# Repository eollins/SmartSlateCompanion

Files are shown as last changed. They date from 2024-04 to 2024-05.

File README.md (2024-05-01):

Introduction
--

[Smart Slate Github Repo](https://github.com/eollins/SmartSlateCompanion/tree/master)

Team Members: Ethan Ollins, Jack Cochran, Alex Peng

For our 4180 project we decided to make our own version of an IOT enabled slate used for film productions. These "Smart Slates", as we have called them, have 6 primary functions.
They are:

1) Display the Roll, Scene, and Take number.
  
2) Keep track of the current time relative to the start of the shoot.
   
3) Keep track of the timestamp of the start of each scene.
   
4) Make it easy for the Assistant Director(will now be referenced as AD) to take notes on the current scene and save them for use while editing.
   
5) Make a nice clap sound in order to sync up the video and audio tracks.
    
6) Automatic time start and stop based on clap

For the purposes of designing this project we broke the problem up into 3 segments: detecting the clap and displaying relevant info, controling the slate and inputting relevant info, and the means with which the AD interfaces with the Smart Slate™️. To accomplish this we decided to not only create a Smart Slate™️ but also a desktop companion app that the AD can use to take notes and interface with the slate.

<a href="http://youtu.be/_YN7Nneg3RY" target="_blank">//-- Video Demo --//</a>

Electrical and Hardware Design
-

List of Parts:
* Raspberry Pi 3b+
* Mbed microcontroller
* 8x 7 segment displays
* 1x Magnet Sensor
* 3x uLCD
* 8x CD4511BE
* 56x 330 Ohm Resistors
* ABS Filament
* Jumper Wires
* Electrical Tape

Connect the parts as dictated in the wiring diagram, pin numbers are labeled appropriately. The 7 Segment display circuitry along with the CD4511BE are repeated 8 times for each individual part. Each resistor in the diagram is a 330 Ohm resistor for each of the led segments in the 7 segment displays.

SmartSlate

The ULCD's display the Roll, Scene, and Take number. The 7 segment displays displays the time and when the magnet sensor is opened and closed the time is stopped and recorded in the companion software.

Print out the two .stl files in the repository under /3D models and fit components as shown. Secure parts with tape as neccessary.

Slate Front
Slate Back

Software
--
To successfully recreate this project you will need to do the following 5 things.

1) Clone this github repo

2) Set up the raspberry pi to be an access point for a LAN, ensuring it uses a static IP address of 192.168.4.1

3) Take the contents of the folder named raspberry pi and copy them onto your raspberry pi, setting the connectToCompanion.py script to run as a background service

4) Take the contents of the folder named mbed and copy them onto your mbed

5) Download QT Creator and then copy the contents of the folder named gui into a new QT project and compile

The SmartSlate works via three distinct components.

1) Raspberry Pi "connectToCompanion" script
The Raspberry Pi inside the slate hosts a wireless access point using the hostapd and dnsmasq libraries. Through its wireless interface, it uses a static local IP address, 192.168.4.1. The connectToCompanion.py script runs as a background service on the Pi, and it simultaneously listens for and accepts TCP connections from users, monitors connections for heartbeats (allowing for timeout detection), maintains a "slate state," and communicates with the mbed. The Raspberry Pi script is a state machine of sorts, cycling between the states of "init" (when the slate is waiting for take information), "ready" (when the slate has received take information and is waiting for the operator to use the clapper), and "clapped" (when the slate has been clapped, the timecode has been reported, and the slate is waiting for notes to be published). The Pi script additionally saves all notes and updates made to them in a local tab-separated values file, which it additionally sends to the companion app. In summary, the primary purpose of the connectToCompanion script is to accept companion connections, communicate with the mbed's sensors and displays, and centralize the notes.

2) SmartSlateCompanion Qt5 C++ application
The SmartSlateCompanion application is used by the second-assistant director (2AD) to push roll, scene, and take information to the slate, as well as to record notes for each take that is completed (along with other useful information such as audio track number and audio device). The SmartSlateCompanion app, written in C++ using the Qt UI library, repeatedly attempts to open a TCP connection to the Raspberry Pi's static IP address until a successful connection is made. This is only possible once the user has connected their computer to the SmartSlate LAN, which is hosted by the Raspberry Pi. Once the companion has connected via port 2024, the user is able to monitor the current state of the slate (init, ready, or clapped). When the user inputs a roll, scene, and take number, the information is sent to the Raspberry Pi over TCP, and the state is updated to "ready." The 2AD then remains idle until the "clapped" state has been reached, after which the 2AD may enter take notes at any time (intended for when the director has called "cut"). Once this takes place, the slate's state is reset, and the relevant notes appear in the companion app. The 2AD may update, clear, or download the notes at any time. In summary, the companion is in the domain of the second assistant director, who is responsible for compiling notes.

3) mbed code
The mbed on the inside of the slate governs the display of received information as well as some elements of the state machine progression. It is connected to the Raspberry Pi via USB, allowing for communication via serial as well as allowing the mbed to receive power. The connectToCompanion script does not begin until the mbed has been properly detected over the serial port. Once connected, the mbed maintains a timecode relative to when it has powered on, using a separate thread to display this precise time on the array of seven-segment displays (with the aid of seven-segment driver chips that reduce the number of pins needed). Additionally, the mbed waits for serial input from the Pi, and once it receives a full set of roll/scene/take numbers (sent by the Pi in a specific format), it displays the received information on the uLCD displays. This then enables the mbed to begin listening for claps, which are detected by a magnet sensor embedded into the clapper arm itself. Once the clap has been registered, the timecode is frozen on the displays and sent back to the Pi, which records the timecode and updates its state to "clapped." Once the Pi sends a "clear" signal over serial, the mbed unfreezes the timecode display and erases the uLCD, and begins waiting for the next take. In summary, the mbed is primarily responsible for managing the physical displays on the slate, receiving pertinent display information from the Pi, and sending pertinent state information back in return.

Setting up a Raspberry PI as an access point
--
The Raspberry Pi, running the Raspbian OS, was configured to serve as a wireless access point. Though it is not connected to a router and therefore does not have access to the Internet, this provides the benefit of allowing hosts, such as a user's laptop, to connect to the Pi wirelessly and communicate via TCP sockets. Through the hostapd and dnsmasq libraries, the Raspberry Pi serves as an access point using its wireless connectivity interface and uses the fixed local IP address of 192.168.4.1. Communication between a user running the SmartSlateCompanion app and the slate itself takes place when the user connects to the SmartSlate network, and the companion application automatically establishes a TCP connection. The Raspberry Pi then serves as a middleman between the user and the visible elements of the slate, which are controlled by an internal mbed.

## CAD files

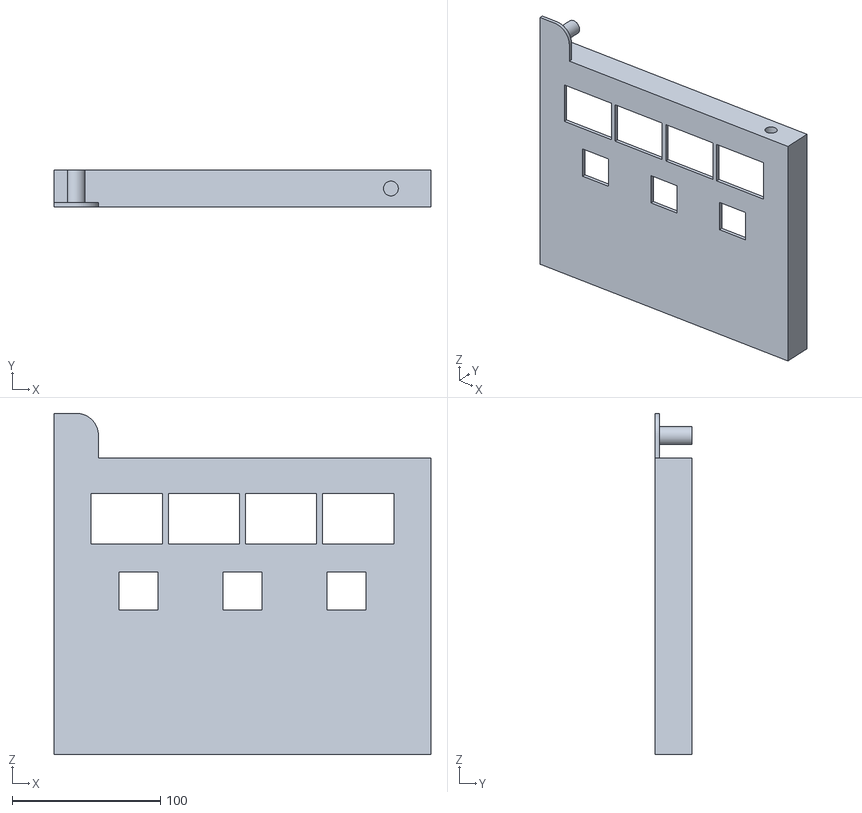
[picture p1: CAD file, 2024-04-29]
3D models/smartslatebody.stl
254.0 x 25.0 x 230.0

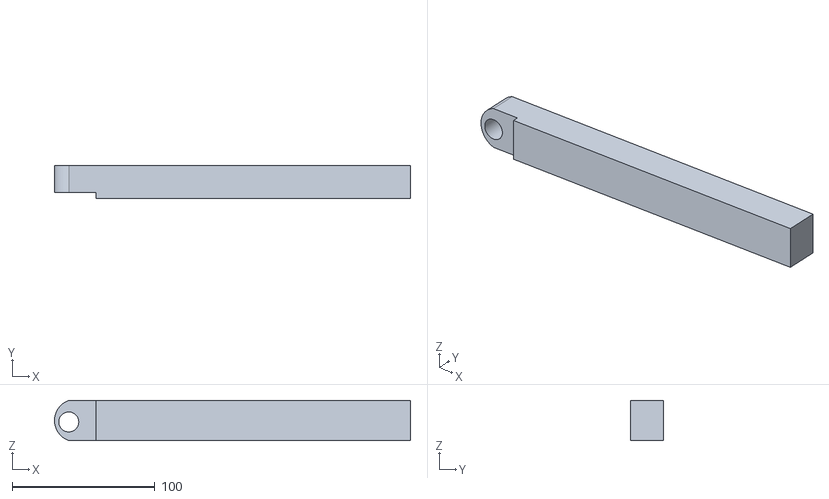
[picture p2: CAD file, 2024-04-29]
3D models/smartslateslapper.stl
249.0 x 23.0 x 28.0

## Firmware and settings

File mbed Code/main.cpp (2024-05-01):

#include "mbed.h"
#include "uLCD_4DGL.h"
#include "string"
#include "rtos.h"
#include "math.h"
#include <climits>

DigitalIn clap(p19);

DigitalOut led1(LED1);
DigitalOut led2(LED2);
DigitalOut led3(LED3);
DigitalOut led4(LED4);

DigitalOut ss1(p24);
DigitalOut ss2(p23);
DigitalOut ss3(p22);
DigitalOut ss0(p21);

DigitalOut disp7(p7);
DigitalOut disp6(p8);
DigitalOut disp5(p6);
DigitalOut disp4(p5);
DigitalOut disp3(p20);
DigitalOut disp2(p18);
DigitalOut disp1(p17);
DigitalOut disp0(p16);

uLCD_4DGL take(p9, p10, p11);
uLCD_4DGL scene(p13, p14, p15);
uLCD_4DGL roll(p28, p27, p26);

volatile int state = 0;
Mutex roll_lock;
Mutex scene_lock;
Mutex take_lock;
Thread clapper;
Thread timecode;

volatile int hour1 = 0, hour0 = 0;
volatile int minute1 = 0, minute0 = 0;
volatile int second1 = 0, second0 = 0;
volatile int deci = 0, centi = 0, milli = 0;

// 0 = init
// 1 = pi ready
// 2 = pi ready, clapper was closed
// 3 = pi ready, clapper was opened
// 4 = pi ready, clapped, waiting

//SPISlave pi(p5, p6, p7, p8);

Serial pi(USBTX, USBRX);

void number_lock(int digit, int lock) {
    switch (digit) {
        case 7:
            disp7 = lock;
            break;
        case 6:
            disp6 = lock;
            break;
        case 5:
            disp5 = lock;
            break;
        case 4:
            disp4 = lock;
            break;
        case 3:
            disp3 = lock;
            break;
        case 2:
            disp2 = lock;
            break;
        case 1:
            disp1 = lock;
            break;
        case 0:
            disp0 = lock;
            break;
    }
}

void set_digit(int digit, int value) {
    number_lock(digit, 0);
    ss3 = value & 8;
    ss2 = value & 4;
    ss1 = value & 2;
    ss0 = value & 1;
    number_lock(digit, 1);
}

void set_display(int d7, int d6, int d5, int d4, int d3, int d2, int d1, int d0) {
    set_digit(7, d7);
    set_digit(6, d6);
    set_digit(5, d5);
    set_digit(4, d4);
    set_digit(3, d3);
    set_digit(2, d2);
    set_digit(1, d1);
    set_digit(0, d0);
}

void clapper_thread() {
    while (1) {
        if (state == 1) {
            if (clap) {
                state = 3;
                while (clap) {}
                state = 4;
                pi.printf("CLAP\n");
                pi.printf("%d%d:%d%d:%d%d.%d%d%d\n", hour1, hour0, minute1, minute0, second1, second0, deci, centi, milli);
                set_display(hour1, hour0, minute1, minute0, second1, second0, deci, centi);

                roll_lock.lock();
                roll.filled_circle(64, 64, 10, RED);
                roll_lock.unlock();

                scene_lock.lock();
                scene.filled_circle(64, 64, 10, RED);
                scene_lock.unlock();

                take_lock.lock();
                take.filled_circle(64, 64, 10, RED);
                take_lock.unlock();

            } else {
                state = 2;
                while (!clap) {}
                state = 3;
                while (clap) {}
                state = 4;
                pi.printf("CLAP\n");
                pi.printf("%d%d:%d%d:%d%d.%d%d%d\n", hour1, hour0, minute1, minute0, second1, second0, deci, centi, milli);
                set_display(hour1, hour0, minute1, minute0, second1, second0, deci, centi);

                roll_lock.lock();
                roll.filled_circle(64, 64, 10, RED);
                roll_lock.unlock();

                scene_lock.lock();
                scene.filled_circle(64, 64, 10, RED);
                scene_lock.unlock();

                take_lock.lock();
                take.filled_circle(64, 64, 10, RED);
                take_lock.unlock();
            }
        }

        if (state == 1) {
            led1 = 1;
            led2 = 0;
            led3 = 0;
            led4 = 0;
        } else if (state == 2) {
            led1 = 0;
            led2 = 1;
            led3 = 0;
            led4 = 0;
        } else if (state == 3) {
            led1 = 0;
            led2 = 0;
            led3 = 1;
            led4 = 0;
        } else if (state == 4) {
            led1 = 0;
            led2 = 0;
            led3 = 0;
            led4 = 1;
        }
    }
}

void timecode_thread() {
    Timer t;
    t.start();

    int overflow_count = 0;
    int overflow_size = 2000000000;
    int offset = 0;

    int new_ms, new_us;
    while (1) {
        if (state != 4) {
            new_ms = t.read_ms();
            new_us = t.read_us();

            if (new_us >= overflow_size) {
                offset += (new_us - overflow_size) / 1000;
                t.reset();
                overflow_count++;
            }

            unsigned long long total_millis = (overflow_count) * (overflow_size / 1000) + new_ms + offset;

            int hours = min((int)(total_millis / 3600000), 99);
            int minutes = min((int)((total_millis / 60000) % 60), 59);
            int seconds = min((int)((total_millis / 1000) % 60), 59);
            int centi_s = min((int)((total_millis / 10) % 100), 99);
            int mill_s = (total_millis % 1000) / 100;

            hour1 = hours / 10; hour0 = hours % 10;
            minute1 = minutes / 10; minute0 = minutes % 10;
            second1 = seconds / 10; second0 = seconds % 10;
            deci = centi_s / 10; centi = centi_s % 10; milli = mill_s;
        
            if (new_ms % 3 == 0) {
                set_display(hour1, hour0, minute1, minute0, second1, second0, deci, centi);
            }
        }
    }
}

int main() {
    clap.mode(PullUp);
    // roll.background_color(GREEN);
    // scene.background_color(BLUE);
    // take.background_color(RED);
    roll.cls();
    scene.cls();
    take.cls();

    set_time(1704085200);

    disp7 = 1;
    disp6 = 1;
    disp5 = 1;
    disp4 = 1;
    disp3 = 1;
    disp2 = 1;
    disp1 = 1;
    disp0 = 1;

    bool clapped = false;
    bool receiving = false;

    string roll_s("");
    string scene_s("");
    string take_s("");

    string old_roll("");
    string old_scene("");
    string old_take("");

    pi.baud(9600);

    string msg("");
    int adding = 0;
    
    char c = ' ';

    clapper.start(clapper_thread);
    timecode.start(timecode_thread);

    while (1) {
        while (pi.readable()) {
            char c = pi.getc();
            msg += c;
            pi.printf(msg.c_str());

            if (c == '@') {
                state = 0;
                msg = "";
                roll_s = "";
                scene_s = "";
                take_s = "";

                roll_lock.lock();
                roll.cls();
                roll_lock.unlock();

                scene_lock.lock();
                scene.cls();
                scene_lock.unlock();

                take_lock.lock();
                take.cls();
                take_lock.unlock();
                
                continue;
            } else if (c == 'R' && adding == 0) {
                adding = 1;
                roll_s = "";
                msg = "";
                
                continue;
            } else if (c == 'S' && adding == 0) {
                adding = 2;
                scene_s = "";
                msg = "";

                continue;
            } else if (c == 'T' && adding == 0) {
                adding = 3;
                take_s = "";
                msg = "";

                continue;
            }

            if (adding == 1) {
                if (c == '~') {
                    adding = 0;

                    roll_lock.lock();
                    roll.color(RED);
                    roll.filled_rectangle(0, 0, 127, 127, 0x0000);
                    roll.locate(3, 3);
                    roll.text_width(6);
                    roll.text_height(6);
                    roll.printf(roll_s.c_str());
                    roll_lock.unlock();
                    msg = "";
                    
                    continue;
                }

                roll_s += c;
                //pi.printf("Adding to roll");

                led1 = 1;
                led2 = 0;
                led3 = 0;
                led4 = 0;
            } else if (adding == 2) {
                if (c == '~') {
                    adding = 0;

                    scene_lock.lock();
                    scene.color(RED);
                    scene.filled_rectangle(0, 0, 127, 127, 0x0000);
                    scene.locate(3, 3);
                    scene.text_width(6);
                    scene.text_height(6);
                    scene.printf(scene_s.c_str());
                    scene_lock.unlock();
                    msg = "";

                    continue;
                }

                scene_s += c;
                //pi.printf("Adding to scene");

                led1 = 0;
                led2 = 1;
                led3 = 0;
                led4 = 0;
            } else if (adding == 3) {
                if (c == '~') {
                    adding = 0;

                    take_lock.lock();
                    take.color(RED);
                    take.filled_rectangle(0, 0, 127, 127, 0x0000);
                    take.locate(3, 3);
                    take.text_width(6);
                    take.text_height(6);
                    take.printf(take_s.c_str());
                    take_lock.unlock();
                    msg = "";

                    if (state == 0) {
                        state = 1;
                    }

                    continue;
                }

                take_s += c;
                //pi.printf("Adding to take");

                led1 = 0;
                led2 = 0;
                led3 = 1;
                led4 = 0;
            }
        }           
    }
}

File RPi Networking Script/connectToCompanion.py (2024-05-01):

import socket
import threading 
import select 
import time 
import signal 
import sys 
import json 
import traceback 
import os
from datetime import date 
from sense_hat import SenseHat
import spidev
import binascii
import serial

# Establish a socket to listen on the static IP.
server = socket.socket(socket.AF_INET, socket.SOCK_STREAM)
server.setsockopt(socket.SOL_SOCKET, socket.SO_REUSEADDR, 1)
server.bind(('192.168.4.1', 2024))
server.listen()
sockets = []
print("Now listening on IP 192.168.4.1")

# Global clap variable.
clap = False

hatOn = False

debug = None
if hatOn:
	debug = SenseHat()

found = False
dev = 0
while not found:
	try:
		mbed = serial.Serial('/dev/ttyACM' + str(dev), 9600)
		found = True
	except:
		print("Didn't find", str(dev) + ", trying other")

		if dev == 0:
			dev = 1
		else:
			dev = 0
print("Found mbed")

# Initialize slate state.
state = {
	"state": "init",
	"roll": "",
	"scene": "",
	"take": "",
	"timecode": "",
	"notes": ""
}

# Thread for checking for temporary claps.
def check_for_claps():
	global clap
	global state

	while True:
		try:
			if state["state"] == "ready":
				print("Reading mbed")
				msg = mbed.readline()
				print("Received", msg)
				if msg[-5:-1].decode() == "CLAP":
					print("Clap detected.")
					if state["state"] == "ready":
						print("Set to clapped!")
						state["state"] = "clapped"
					
					print("Waiting for timecode")
					timecode = mbed.readline()
					print("Got the timecode")
					state["timecode"] = timecode.decode()[:-1]
		except:
			print("mbed not found")

# Closes all sockets once interrupted.
def signal_handler(sig, frame):
	print("Interrupted: closing all sockets.")
	for s in sockets:
		print("Closing", s[1])
		s[0].close()
	print("Closing listener")
	server.close()
	sys.exit(0)

signal.signal(signal.SIGINT, signal_handler)

# Connection thread.
def establish_connection(sock, addr):
	global clap
	global state

	connected = True
	if hatOn:
		debug.clear((0, 255, 0))
	
	while connected:
		if state['state'] == "ready" and hatOn:
			debug.clear((0, 255, 0))
		elif state['state'] == "clapped" and hatOn:
			debug.clear((0, 0, 255))
		elif state['state'] == "init" and hatOn:
			debug.clear((255, 255, 0))

		try:
			ready = select.select([sock], [], [], 1)
			start = time.time()
			while (not ready[0]):
				if (time.time() - start >= 5):
					print("Timeout", addr)
					sock.close()
					connected = False 
				ready = select.select([sock], [], [], 10)

			if ready[0] and connected:
				data = sock.recv(1024)

				if "Heartbeat" not in data.decode():
					print("Received", data.decode())

				data_s = data.decode()
				if data_s is not None:
					json_dict = json.loads(data_s)
					if json_dict["command"] == "PushToSlate":
						state["roll"] = json_dict["payload"]["roll"]
						state["scene"] = json_dict["payload"]["scene"]
						state["take"] = json_dict["payload"]["take"]
						state["message"] = "Successfully updated scene/take nums"
						print("Updated take info to", state["roll"], state["scene"], state["take"])
						state["state"] = "ready"

						try:
							m = "@R" + state["roll"] + "~S" + state["scene"] + "~T" + state["take"] + "~"
							print(m)
							mbed.write((m).encode('utf-8'))
							print("Sent to displays")
						except:
							print("mbed was gone")

					elif json_dict["command"] == "PushNotes":
						if state["state"] == "clapped":
							state["state"] = "init"
							notes_to_write = json_dict["payload"]
							d = date.today()
							file_name = "/home/pi/" + d.strftime("%d_%m_%y.txt")

							if not os.path.exists(file_name):
								file = open(file_name, 'x')
								file.close()

							file = open(file_name, 'a+')

							if state["roll"] != None and state["scene"] != None and state["take"] != None and notes_to_write["audio"] != None and notes_to_write["device"] != None and notes_to_write["notes"] != None:
								file.write(state["roll"] + "\t")
								file.write(state["scene"] + "\t")
								file.write(state["take"] + "\t")
								file.write(notes_to_write["audio"] + "\t")
								file.write(notes_to_write["device"] + "\t")
								file.write(state["timecode"] + "\t")
								file.write(notes_to_write["notes"] + "\n")

							file.close()
							print(json_dict["payload"])
							print("Took notes", json_dict["payload"])
			
							try:
								mbed.write(("@").encode('utf-8'))
								print("Sent reset")
							except:
								print("mbed was gone")

					elif json_dict["command"] == "ResetTake":
						if state["state"] != "init":
							state["state"] = "init"
							state["roll"] = ""
							state["scene"] = ""
							state["take"] = ""
							state["message"] = ""
							print("Reset take info")

					elif json_dict["command"] == "UpdateNotes":
						pl = json_dict["payload"]
						notes = state["notes"]
						lines = notes.split("\n")
						cols = lines[int(pl["row"])].split('\t')
						cols[int(pl["column"])] = pl["new"]
						newLine = "\t".join(cols)
						lines[int(pl["row"])] = newLine
						newNotes = "\n".join(lines)

						d = date.today()
						file = "/home/pi/" + d.strftime("%d_%m_%y.txt")
						f = open(file, "w")
						f.write(newNotes)
						f.close()
						state["notes"] = newNotes

					elif json_dict["command"] == "ClearNotes":
						d = date.today()
						file = "/home/pi/" + d.strftime("%d_%m_%y.txt")
						f = open(file, "w")
						f.write("")
						f.close()
						state["notes"] = ""

				d = date.today()
				file = "/home/pi/" + d.strftime("%d_%m_%y.txt")
				if os.path.exists(file):
					f = open(file, "r")
					notes = f.read()
					f.close()
					state["notes"] = notes
				else:
					state["notes"] = "No note file"

				sock.send((json.dumps(state)).encode('utf-8'))

		except Exception as e:
			if hatOn:
				debug.clear((255, 0, 0))
			traceback.print_exc()
			print("Lost", addr, e)
			sock.close()
			connected = False

clap_checker = threading.Thread(target=check_for_claps)
clap_checker.daemon = True
clap_checker.start()

while True:
	conn, addr = server.accept()
	sockets.append((conn, addr))
	print("Accepted connection from", addr[0], addr[1])
	handle = threading.Thread(target=establish_connection, args=(conn,addr))
	handle.daemon = True
	handle.start()

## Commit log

2024-04-29 added stl's for slate model
    [smartslatebody.stl, smartslateslapper.stl]
2024-05-01 Added notes clear and download buttons
2024-05-01 added folders to create more understandable file structer
    [smartslatebody.stl, smartslateslapper.stl]
2024-05-01 Fixed reorganization
    [smartslatebody.stl, smartslateslapper.stl]
